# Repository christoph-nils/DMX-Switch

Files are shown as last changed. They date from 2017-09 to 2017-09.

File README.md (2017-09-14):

# DMX-Switch

[Hier ist das Projekt inklusive Bilder](http://christoph-nils.de/elektronik/dmx-switch/) bzw. [hier](http://data.christoph-nils.de/diverses/DMX-Switch.zip)  
Ein simpler DMX-Switch für die Hutschiene. Zur Adressierung wird ein Taster gedrückt und speichert die erste Adresse mit DMX-Wert > 128 als Startadresse.  
Ein Kanal kann auch zur Signalisierung eines gültigen DMX-Signals verwendet werden.  
Der Source-Code basiert auf diesem [Code](https://www.mikrocontroller.net/topic/185804)  
Lizenz: http://creativecommons.org/licenses/by-nc/3.0/de/

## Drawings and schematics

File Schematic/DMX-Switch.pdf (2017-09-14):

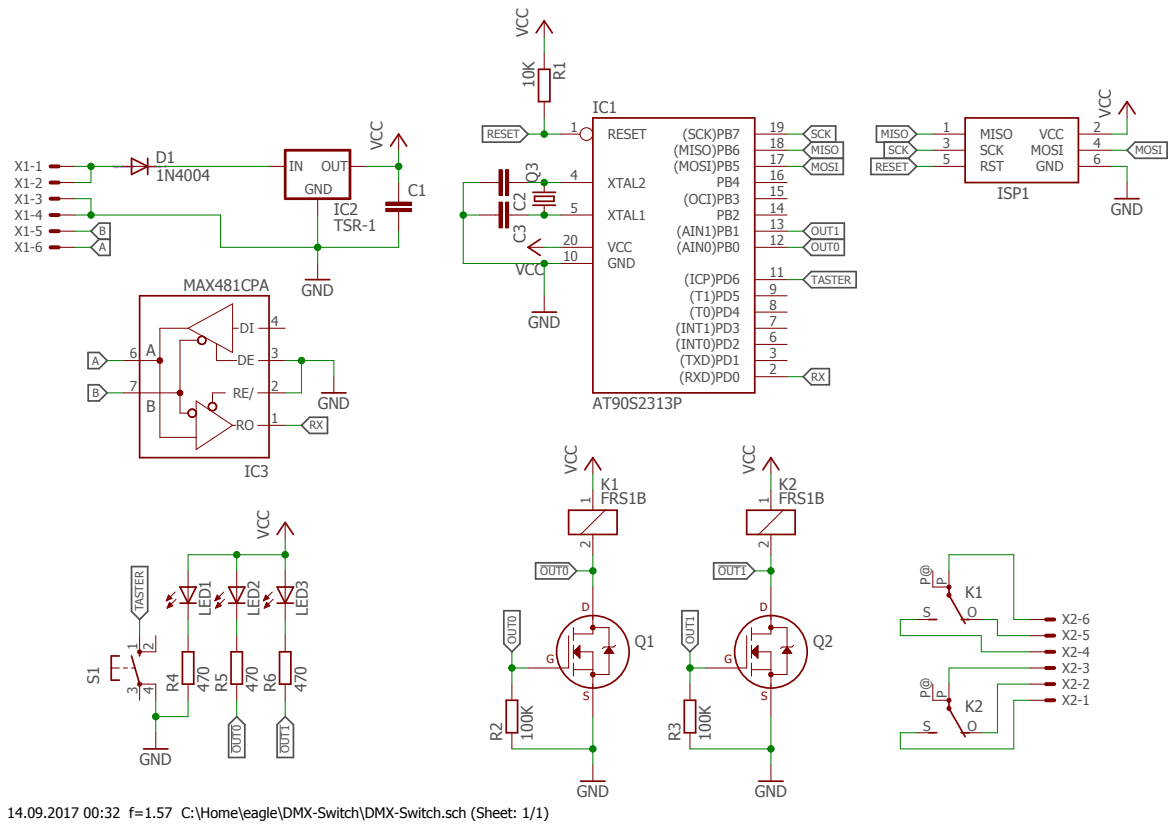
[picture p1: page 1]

14.09.2017 00:32 f=1.57 C:\Home\eagle\DMX-Switch\DMX-Switch.sch (Sheet: 1/1)

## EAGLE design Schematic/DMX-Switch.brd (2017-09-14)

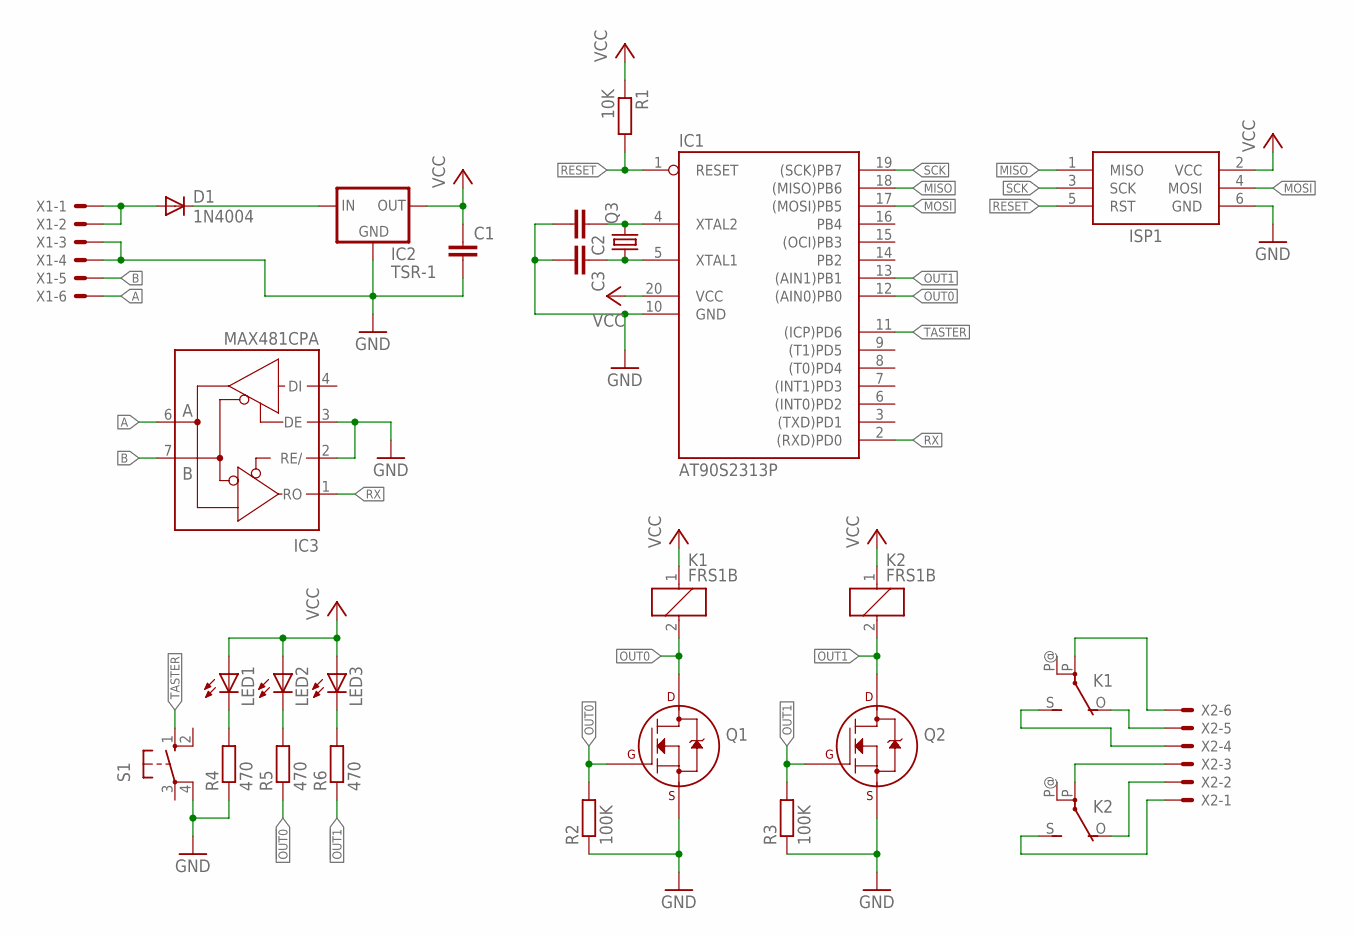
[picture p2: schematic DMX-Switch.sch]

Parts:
C1, C2, C3: C-EU025-024X044; C025-024X044
D1: 1N4004; DO41-10
IC1: AT90S2313P; DIL20
IC2: TSR-1
IC3: MAX481CPA; DIL08
ISP1: AVRISP-BOX
K1, K2: FRS1B
LED1, LED2, LED3: LED5MM
Q1, Q2: 2N7000_TO92; TO-92
Q3: CRYSTALHC49S; HC49/S
R1: 10K; 0204/7
R2, R3: 100K; 0204/7
R4, R5, R6: 470; 0204/7
S1: 10-XX; B3F-10XX
X1, X2: KK-156-6

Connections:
!OUT0: K1.2, Q1.3 (D), R5.1
!OUT1: K2.2, Q2.3 (D), R6.1
A: IC3.6 (A), X1.6
B: IC3.7 (B), X1.5
GND: C1.2, C2.2, C3.2, IC1.10 (GND), IC2.2 (GND), IC3.2 (RE/), IC3.3 (DE), IC3.5 (GND), ISP1.6 (GND), Q1.1 (S), Q2.1 (S), R2.1, R3.1, R4.1, S1.4 (P1), X1.3, X1.4
MISO: IC1.18 ((MISO)PB6), ISP1.1 (MISO)
MOSI: IC1.17 ((MOSI)PB5), ISP1.4 (MOSI)
unnamed: D1.A, X1.1, X1.2
unnamed: D1.C, IC2.1 (IN)
unnamed: C3.1, IC1.5 (XTAL1), Q3.1
unnamed: C2.1, IC1.4 (XTAL2), Q3.2
unnamed: LED1.K (C), R4.2
unnamed: LED2.K (C), R5.2
unnamed: LED3.K (C), R6.2
unnamed: K1.S, X2.4
unnamed: K1.O, X2.5
unnamed: K1.P, X2.6
unnamed: K2.P, X2.3
unnamed: K2.O, X2.2
unnamed: K2.S, X2.1
OUT0: IC1.12 ((AIN0)PB0), Q1.2 (G), R2.2
OUT1: IC1.13 ((AIN1)PB1), Q2.2 (G), R3.2
RESET: IC1.1 (RESET), ISP1.5 (RST), R1.2
RX: IC1.2 ((RXD)PD0), IC3.1 (RO)
SCK: IC1.19 ((SCK)PB7), ISP1.3 (SCK)
TASTER: IC1.11 ((ICP)PD6), S1.1 (S)
VCC: C1.1, IC1.20 (VCC), IC2.3 (OUT), IC3.8 (VCC), ISP1.2 (VCC), K1.1, K2.1, LED1.A, LED2.A, LED3.A, R1.1

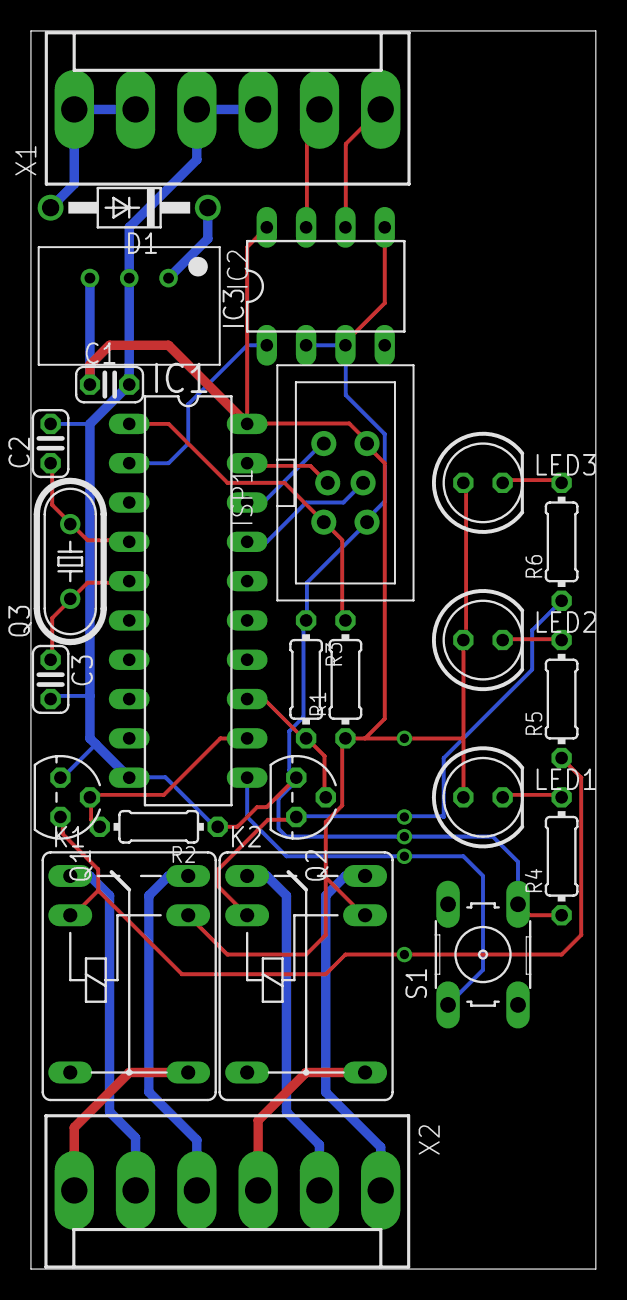
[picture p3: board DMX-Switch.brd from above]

Board: 2 copper layers, 36.5 x 80.0 mm, 25 parts (0 on the bottom side), 27 nets.

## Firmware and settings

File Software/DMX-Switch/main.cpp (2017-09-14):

/**

 * Original https://www.mikrocontroller.net/topic/185804
 * Editiert von Christoph Nils Schäfer <mail@christoph-nils.de>
 * DMX Switch zur Signalisierung der DMX Verfügbarkeit
 * und ein per DMX schaltbarer Kanal
 * Startadresse per Taster und DMX einstellbar

 * DMX Receiver 
 * 2*8bit linear pwm, 2*16bit exponential pwm
 *
 * @author Andi Dittrich <andi.dittrich@a3non.org>
 * @website http://www.a3non.org
 * @modified 31.07.2010
 * @license CC BY-NC
 * @license http://creativecommons.org/licenses/by-nc/3.0/de/
 * @target AtTiny2313
 * @cpu 16MHz
*/
#define F_CPU 16000000UL

#include <avr/interrupt.h>
#include <stdio.h>
#include <inttypes.h>
#include <avr/io.h>
#include <avr/pgmspace.h>
#include <avr/wdt.h>
#include <util/delay.h>
#include <avr/eeprom.h>
#include "mydefs.h"

// number of receiving channels
#define DMX_CHANNELS 1

//PD0	RX
//PD6	Taster Set-CH-n
//PB0	Relais DMX-OK
//PB1	Relais DMX-CH-n

#define	RX_PORT			SBIT( PORTD, 0 )
#define	RX_DDR			SBIT( DDRD,  0 )
#define	Taster_PORT		SBIT( PORTD, 6 )
#define	Taster_PIN		SBIT( PIND,  6 )
#define	Taster_DDR		SBIT( DDRD,  6 )
#define	Relais_0_OUT	SBIT( PORTB, 0 )
#define	Relais_0_DDR	SBIT( DDRB,  0 )
#define	Relais_1_OUT	SBIT( PORTB, 1 )
#define	Relais_1_DDR	SBIT( DDRB,  1 )

// DMX address
volatile uint16_t DMXAddress = 1;

// dmx storage array
volatile uint8_t dmx_data[DMX_CHANNELS];

// dmx states
enum {IDLE = 0, BREAK, READ, SETADDRESS};

// actual dmx state
volatile uint8_t DMXState = IDLE;

// valid sequence
volatile uint8_t VALID_DATA = 0;

// channel input read count
volatile uint16_t DMXFrameCount = 0;


// MAIN
int main(){
	// disable ISR
	cli();
	
	RX_DDR = 0;
	RX_PORT = 0;
	Taster_DDR = 0;
	Taster_PORT = 1;
	Relais_0_OUT = 0;
	Relais_0_DDR = 1;
	Relais_1_OUT = 0;
	Relais_1_DDR = 1;

	// 250k baud - 16MHz - U2X=0
	UBRRL = 3;
	UBRRH = 0;
	
	
	// UART CONTROL
	// 7:0 - RXC - USART Receive Complete
	// 6:0 - TXC - USART Transmit Complete
	// 5:0 - UDRE - USART Data Register Empty
	// 4:0 - FE - Frame Error
	// 3:0 - DOR - Data OverRun
	// 2:0 - UPE - USART Parity Error
	// 1:0 - U2X - Double the USART Transmission Speed
	// 0:0 - MPCM - Multi-processor Communication Mode
	UCSRA = 0b00000000;
	
	// 7:0 - reserved
	// 6:0 - UMSEL - async operation
	// 5:0 - UPM1 - no paritiy
	// 4:0 - UPM0 - no paritiy
	// 3:1 - USBS - 2 stop bits
	// 2:1 - UCSZ1 - 8bit mode
	// 1:1 - UCSZ0 - 8bit mode
	// 0:0 - UCPOL - clock polarity, rising edge
	UCSRC = 0b00001110;

	// UART CONTROL
	// 7:1 - RXCIE - RX Complete Interrupt Enable
	// 6:0 - TXCIE - TX Complete Interrupt Disable
	// 5:0 - UDRIE - USART Data Register Empty Interrupt Disable
	// 4:1 - RXEN - Receiver Enable
	// 3:0 - TXEN - Transmitter Disable
	// 2:0 - UCSZ2 - 8bit mode
	// 1:0 - RXB8 - Receive Data Bit 8
	// 0:0 - TXB8 - Transmit Data Bit 8
	UCSRB = 0b10010000;

	// WATCHDOG - 4s
	// 7:0 - Watchdog Interrupt Flag
	// 6:1 - Watchdog Interrupt Enable
	// 5:1 - Watchdog Timer Prescaler3
	// 4:1 - Watchdog Change Enable
	// 3:0 - Watchdog System Reset Disable
	// 2:0 - Watchdog Timer Prescaler2
	// 1:0 - Watchdog Timer Prescaler1
	// 0:0 - Watchdog Timer Prescaler0
	WDTCR = 0b01110000;	

	// reset watchdog
	MCUSR &= ~(1<<WDRF);
			
	// initialize DMX State
	DMXState = IDLE;

	// initialize data array
	for (uint8_t i=0;i<DMX_CHANNELS;i++){
		dmx_data[i]= 0;
	}

	//Load DMX Address
	DMXAddress = eeprom_read_word(0);

	// enable dmx rx
	sei();

	// main loop
	while (true){
		// assign channels
		if (VALID_DATA){
			// on valid frame, assign values to ouputs
			
			if(dmx_data[0]>=128)
				Relais_1_OUT = 1;
			else
				Relais_1_OUT = 0;
			Relais_0_OUT = 1; //DMX OK
		}else{
			// deactivate all outputs on dmx-line error
			
			Relais_1_OUT = 0;	
			Relais_0_OUT = 0; //DMX not OK
		}

	}

	return 1;
};


/**
 *	ISR SECTION
 */
// DMX RECEIVE
ISR (USART_RX_vect){
	// store ucsra register for frame error flag
	uint8_t statusreg = UCSRA;

	// get data
	uint8_t DMXDataByte = UDR;

	// check for break (error flag is set)
	if (bit_is_set(statusreg, FE)){
		// reset frame counter
		DMXFrameCount = 0;

		// set break status
		DMXState = BREAK;
	
		// abort on frame error
		return;
	}

	// state machine	
	switch (DMXState){
		case BREAK:
			// check for valid startbyte
			DMXState = (DMXDataByte == 0) ? READ : IDLE;
			if(DMXState==READ&&Taster_PIN==0) DMXState = SETADDRESS;
			break;

		case IDLE:
			// do nothing -> wait for break
			break;

		case READ:
			// increment frame count
			DMXFrameCount++;				
			
			// wait for dmx address
			if (DMXFrameCount>=DMXAddress){
				// store value in array
				dmx_data[DMXFrameCount-DMXAddress] = DMXDataByte;
			}
				
			// wait for end of reading channels
			if (DMXFrameCount >= DMXAddress+DMX_CHANNELS-1){
				// activate PWM/Ouput updates
				VALID_DATA = 1;
					
				// set status idle => no action
				DMXState = IDLE;
					
				// reset watchdog
				wdt_reset();
			}			

			break;
		case SETADDRESS:
			// increment frame count
			DMXFrameCount++;
			if(DMXDataByte>=128)
			{
				//Save DMX Address
				eeprom_write_word(0, DMXFrameCount);
				DMXAddress = DMXFrameCount;
				// reset watchdog
				wdt_reset();
				Relais_1_OUT = 0;
				_delay_ms(200);
				Relais_1_OUT = 1;
				_delay_ms(200);
				Relais_1_OUT = 0;
				_delay_ms(200);
				Relais_1_OUT = 1;
				_delay_ms(200);
				Relais_1_OUT = 0;
			}

			if(DMXFrameCount >= 512)
			// set status idle => no action
			DMXState = IDLE;

			// reset watchdog
			wdt_reset();
			break;
	}
}

// Watchdog ISR
ISR(WDT_OVERFLOW_vect){
	// deactivate outputs
	VALID_DATA = 0;
}
